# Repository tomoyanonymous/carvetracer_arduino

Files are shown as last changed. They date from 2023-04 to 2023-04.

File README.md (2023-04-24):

# Simple Curve Tracer Shield for Arduino Uno

A shield circuit board for Arduino Uno to analyze the characteristics of a transistor of FET with minimal components.

2023.04 Matsuura Tomoya

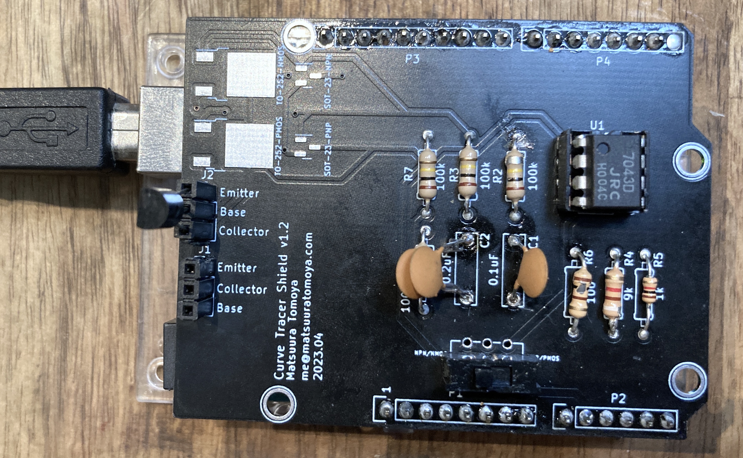
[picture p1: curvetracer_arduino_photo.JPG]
a photo of Curve Tracer Shield for Arduino Uno.


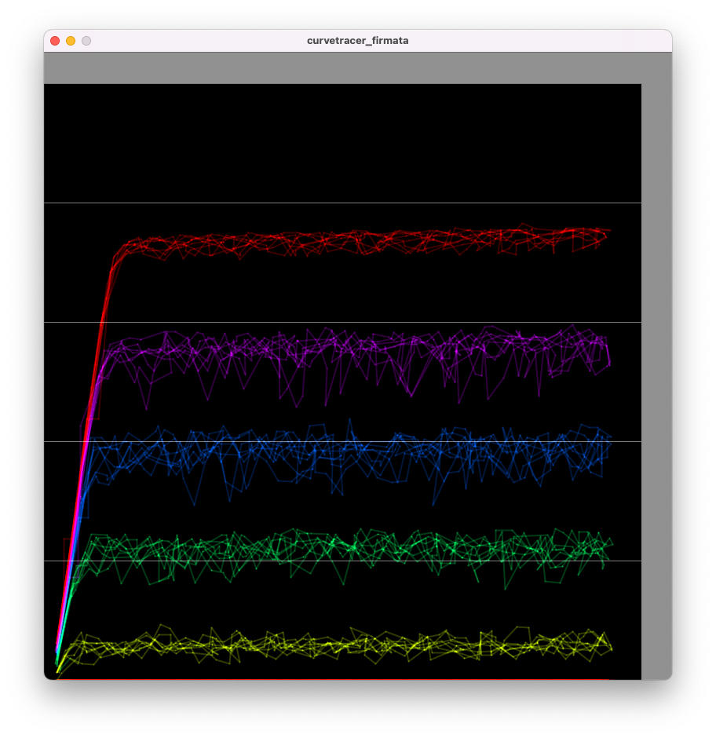
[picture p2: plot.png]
screenshot of the Plotter app with Processing


## Required Components

- Rail-to-Rail Op Amp(DIP8 Package) x1
- Resistors
    - 100k x 5
    - 1k x 1
    - 9k x 1
- Capacitors
    - 0.1uF(104) x 1
    - 0.2uF(204) x 1
- SPDT Switch(or, 3-Pin header w/ Jumper Pin)
- 3 Pin Deep Socket for Transistor x 2
- 2.54mm Pin Header for Arduino Socket

## Required Softwares

- Arduino IDE
- Processing
- KiCad

## How To Use the Shield

1. Connect Arduino to PC
1. Open Examples->Firmata->StandardFirmata
1. Upload it
1. Stack the shield onto Arduino
1. Check the polarity of the slide switch depending on what types of transistor you are going to test(NPN/NMOS or PNP/PMOS).
1. Open curvetrace_firmata.pde with Processing and run it.
1. Hit "s" key and it will start plotting.

## Reference 

This project is heavily based on the Project below.

**Arduino BiCMOS Curve Tracer by Don Sauer**

http://www.idea2ic.com/BiCmosCurveTracer/Arduino%2520BiCmos%2520Curve%2520Tracer.html

The hardware structure is mostly the same. 200k resistor is replaced with 100k resistor*2 for the simplicity.

The original software uses raw serial connection between Arduino and Processing. I merged the two codes into 1 Processing sketch by using [Firmata](https://docs.arduino.cc/hacking/software/FirmataLibrary), the multi-purpose serial protocol for controlling arduino.

Instead, the function of exporting raw data for plotting with external application (like Octave and Scilab) is omitted.

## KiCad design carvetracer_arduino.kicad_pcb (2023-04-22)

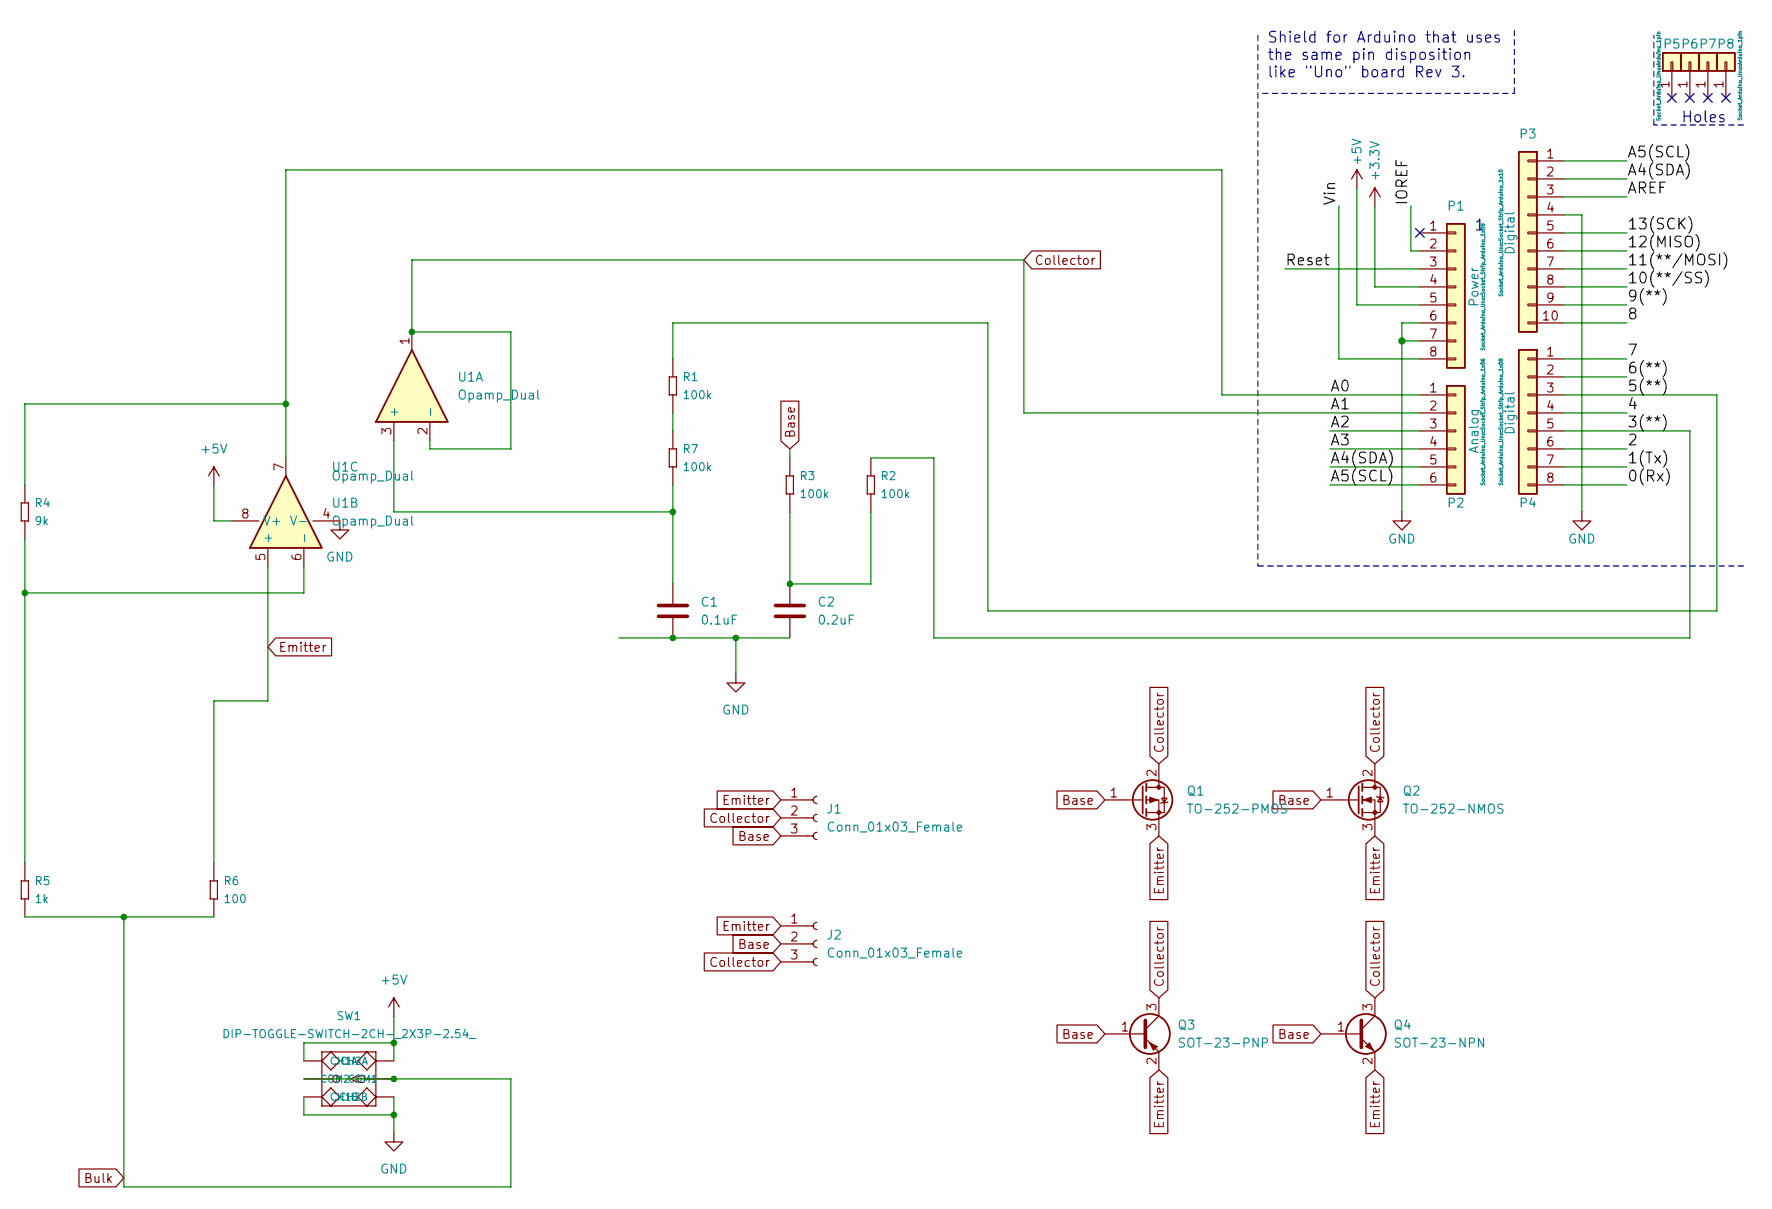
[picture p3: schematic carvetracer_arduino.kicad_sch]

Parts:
C1: 0.1uF; C_Rect_L9.0mm_W2.5mm_P7.50mm_MKT
C2: 0.2uF; C_Rect_L9.0mm_W2.5mm_P7.50mm_MKT
J1, J2: Conn_01x03_Female; PinHeader_1x03_P2.54mm_Vertical
P1: Power; Socket_Strip_Arduino_1x08
P2: Analog; Socket_Strip_Arduino_1x06
P3: Digital; Socket_Strip_Arduino_1x10
P4: Digital; Socket_Strip_Arduino_1x08
P5, P6, P7, P8: CONN_01X01; Arduino_1pin
Q1: TO-252-PMOS; TO-252-2
Q2: TO-252-NMOS; TO-252-2
Q3: SOT-23-PNP; SOT-23
Q4: SOT-23-NPN; SOT-23
R1, R2, R3, R7: 100k; PR-D2.3XL6.5MM; MPN FHCFR-1_4W-101J
R4: 9k; PR-D2.3XL6.5MM; MPN FHCFR-1_4W-101J
R5: 1k; PR-D2.3XL6.5MM; MPN FHCFR-1_4W-101J
R6: 100; PR-D2.3XL6.5MM; MPN FHCFR-1_4W-101J
SW1: DIP-TOGGLE-SWITCH-2CH-_2X3P-2.54_; SW6-2.54-9.0X3.5X3.2+2.0MM; MPN MS-22D18 G2 ROHS
U1: Opamp_Dual; DIP-8_W7.62mm_LongPads

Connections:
+3V3: P1.4
+5V: P1.5, SW1.CH1A, SW1.CH2A, U1.8 (V+)
/0(Rx): P4.8
/1(Tx): P4.7
/2: P4.6
/3(**): P4.5, R2.2
/4: P4.4
/5(**): P4.3, R1.2
/6(**): P4.2
/7: P4.1
/8: P3.10
/9(**): P3.9
/10(**/SS): P3.8
/11(**/MOSI): P3.7
/12(MISO): P3.6
/13(SCK): P3.5
/A0: P2.1, R4.2, U1.7
/A2: P2.3
/A3: P2.4
/A4(SDA): P2.5, P3.2
/A5(SCL): P2.6, P3.1
/AREF: P3.3
/IOREF: P1.2
/Reset: P1.3
/Vin: P1.8
Base: J1.3, J2.2, Q1.1 (G), Q2.1 (G), Q3.1 (B), Q4.1 (B), R3.2
Bulk: R5.1, R6.1, SW1.COM1, SW1.COM2
Collector: J1.2, J2.3, P2.2, Q1.2 (D), Q2.2 (D), Q3.3 (C), Q4.3 (C), U1.1, U1.2 (-)
Emitter: J1.1, J2.1, Q1.3 (S), Q2.3 (S), Q3.2 (E), Q4.2 (E), R6.2, U1.5 (+)
GND: C1.2, C2.2, P1.6, P1.7, P3.4, SW1.CH1B, SW1.CH2B, U1.4 (V-)
unnamed: C1.1, R7.1, U1.3 (+)
unnamed: C2.1, R2.1, R3.1
unnamed: R1.1, R7.2
unnamed: R4.1, R5.2, U1.6 (-)

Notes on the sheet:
Holes
Shield for Arduino that uses the same pin disposition like "Uno" board Rev 3.

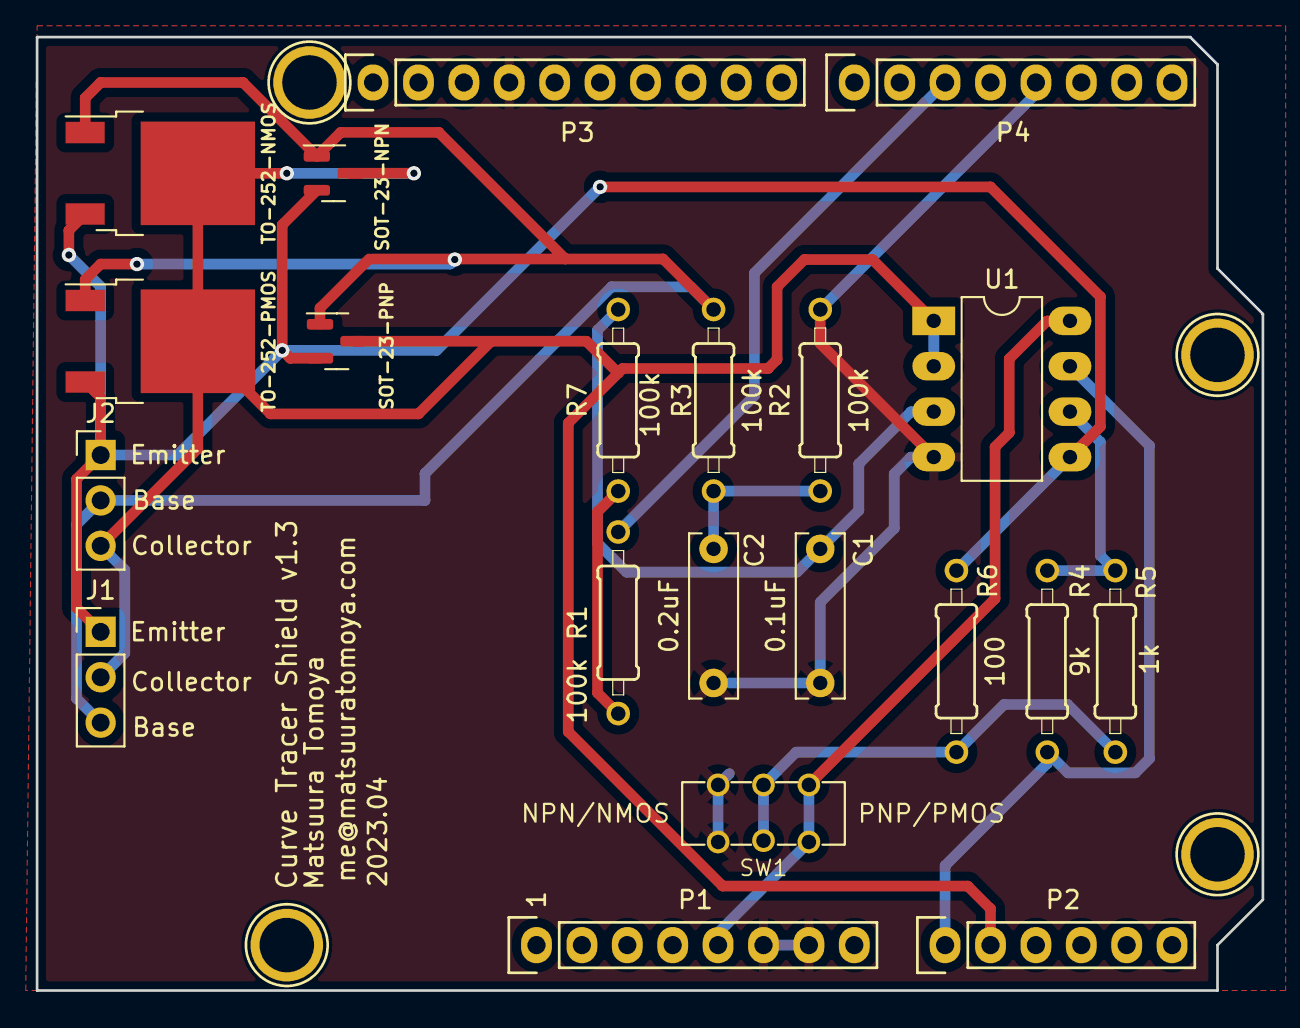
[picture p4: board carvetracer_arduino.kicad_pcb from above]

Board: 2 copper layers, 68.6 x 53.3 mm, 25 parts (0 on the bottom side), 15 nets.

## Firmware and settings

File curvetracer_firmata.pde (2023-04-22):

import processing.serial.*;
import cc.arduino.*;
import org.firmata.*;

Arduino arduino;
final int TRI_PIN = 5;  // TriAngle Wave      at D5
final int VG_PIN = 3;   // Voltage step port  at D3
int tri_v = 0;    // Tri value
int step_v = 0;    // Step Value
int LED_PIN = 10;
final int slope_c=4;
int slope = slope_c;
final int SAMPLES = 2048;
int read_point;
boolean reading=false;
final int step_repeat=1;
int step_repeat_cnt = 0;
int hue = 0;


class PlotData {
  float x=0;
  float y=0;
}
//PlotData[] points;
PlotData tmp;

void initArduino() {
  String[] hosts = Arduino.list();
  println(hosts);
  for (int i=0; i<hosts.length; i++) {
    if (hosts[i].contains("tty.usbmodem")) {
      arduino = new Arduino(this, hosts[i], 57600);
      println("connected");
      delay(50);
      arduino.pinMode(TRI_PIN, Arduino.OUTPUT);
      arduino.pinMode(VG_PIN, Arduino.OUTPUT);
      arduino.pinMode(LED_PIN, Arduino.OUTPUT);
    }
  }
  if (arduino==null) {
    println("no hosts, exit");
    noLoop();
  }
}
void setup()
{
  size(800, 800);
  colorMode(HSB);

  initArduino();
  tmp = new PlotData();
  //points = new PlotData[SAMPLES];
}

void draw()
{

  if (reading) {
    tri_v = tri_v + slope;
    arduino.analogWrite(TRI_PIN, tri_v);          // will be PWM 488 Hz
    arduino.analogWrite(VG_PIN, step_v);           // will be PWM 488 Hz
    hue = step_v;
    strokeWeight(2);
    strokeJoin(ROUND);
    stroke(color(hue, 255, 255), 255/(step_repeat+1)); // color to draw

    int collector_v = 0;
    int tri_read = 0;
    final int read_repeat=6;
    for (int i=0; i<read_repeat; i++) {
      collector_v +=arduino.analogRead(0);
      tri_read += arduino.analogRead(1);
      delay(5);
    }
    println("step_v: ", step_v, "collector_v", collector_v, "tri_read", tri_read);
    float x=map(float(tri_read), 0, read_repeat*1023, 0, width*.95);
    float y=map(float(collector_v), 0, read_repeat*1023, 0, height*.95);


    line(tmp.x, height - tmp.y, x, height - y);  // draw the line:
    tmp.x = x;
    tmp.y = y;


    if (tri_v > 251) {
      slope = -slope_c;
    }
    if (tri_v < 1) {
      slope = slope_c;
      step_repeat_cnt+=1;
      if (step_repeat_cnt>step_repeat) {
        step_repeat_cnt=0;
        step_v += int(255 / 5);
      }
    }
    if (step_v > 255) {
      step_v = 0;
      reading=false;
      println("finished");
    }
  }
  //read_point+=1;
}

void keyPressed() {
  if (key == 's' || key == 'S') {
    blendMode(BLEND);

    reading=true;
    background(145);
    fill(0);
    rect(0, height*0.05, width*0.95, height*0.95);
    for (int i=0; i<5; i++) {
      stroke(125);
      strokeWeight(1);
      float y =  height - height*0.95* float(i+1) / 5.0;
      line(0, y, width*0.95, y);
    }

    tmp.x = 0;
    tmp.y = 0;
    println("started");
    blendMode(ADD);
  }
}
